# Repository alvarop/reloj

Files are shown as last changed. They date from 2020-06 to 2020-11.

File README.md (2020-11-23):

# Reloj - 7400 Series Digital Clock

This project was inspired by my dad's university digital systems project from the late 1970's. I found the writeup and schematic and decided to try and re-create it. You can see the results of the breadboard reproduction and explanations in [this twitter thread.](https://twitter.com/alvaroprieto/status/1239990814320680960)

After a while, I figured it would be fun to make a soldering kit out of it, which resulted in this.

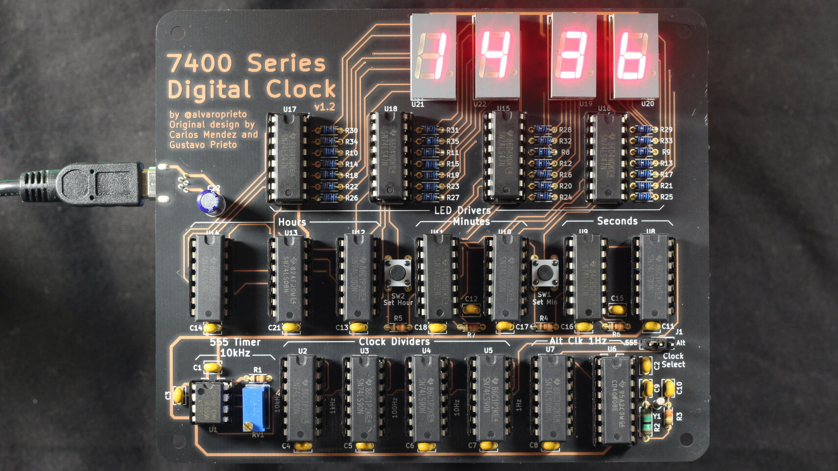
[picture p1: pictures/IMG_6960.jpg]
Reloj v1.2


The design is fairly close to the original, but with the addition of a crystal-backed alternate clock source. The 555 timer clock source works, but drifts like crazy, so if you want to use it as an actual clock, you still can with the alt source.

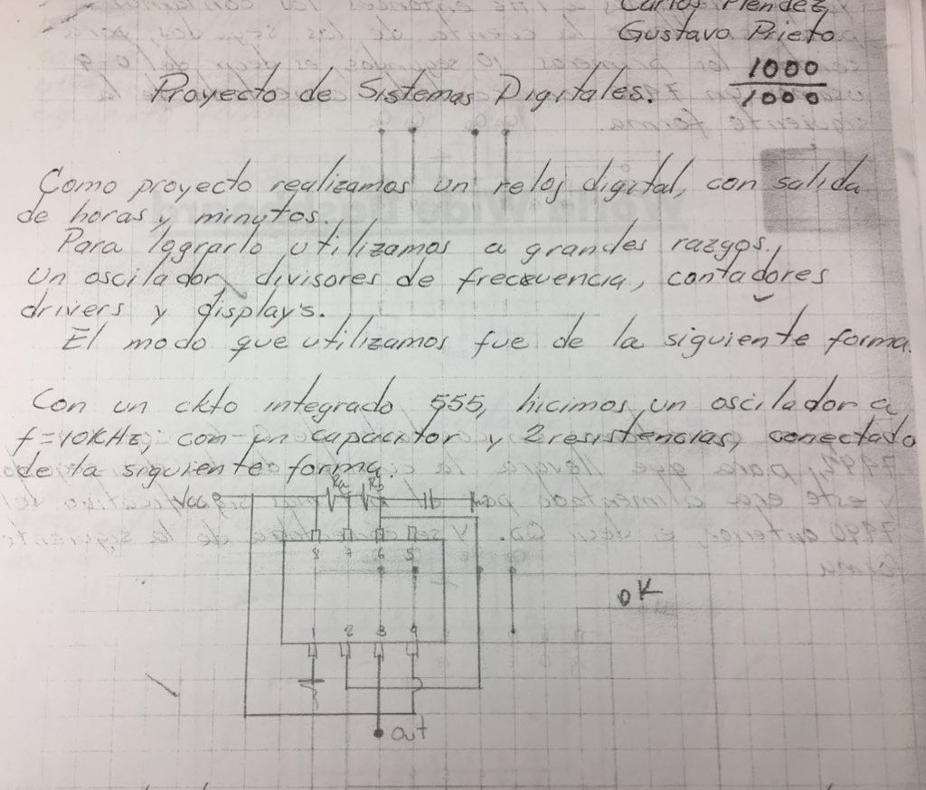
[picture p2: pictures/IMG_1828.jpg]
Paper front page


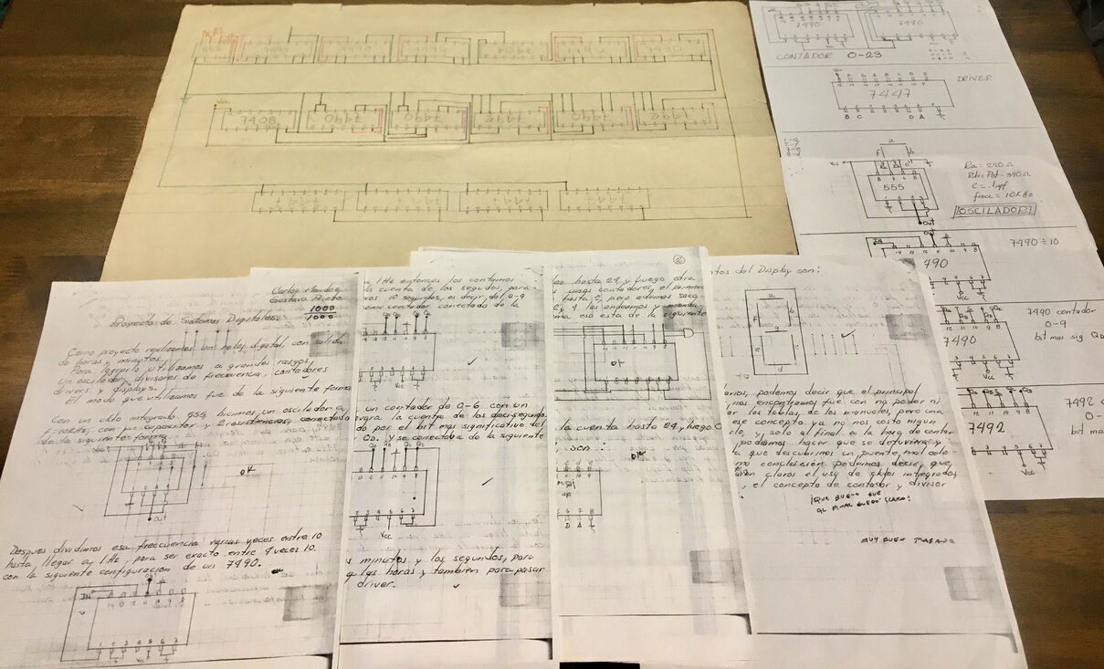
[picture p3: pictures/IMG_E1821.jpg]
Papers


If you want to take a look at the actual paper, you can see the scanned version [here](files/sistemas_digitales.pdf).

## Design Files
You can get the latest files in the [github releases](https://github.com/alvarop/reloj/releases).

For v1.2, you can use my [OSHPark shared project](https://oshpark.com/shared_projects/LdUSEX5V) or by grabbing the gerbers from the release.

## Assembly Instructions
You can find semi-detailed assembly instructions [here](INSTRUCTIONS.md).

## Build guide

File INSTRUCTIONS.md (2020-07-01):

# Reloj v1.2 Assembly Instructions

## Gather Materials
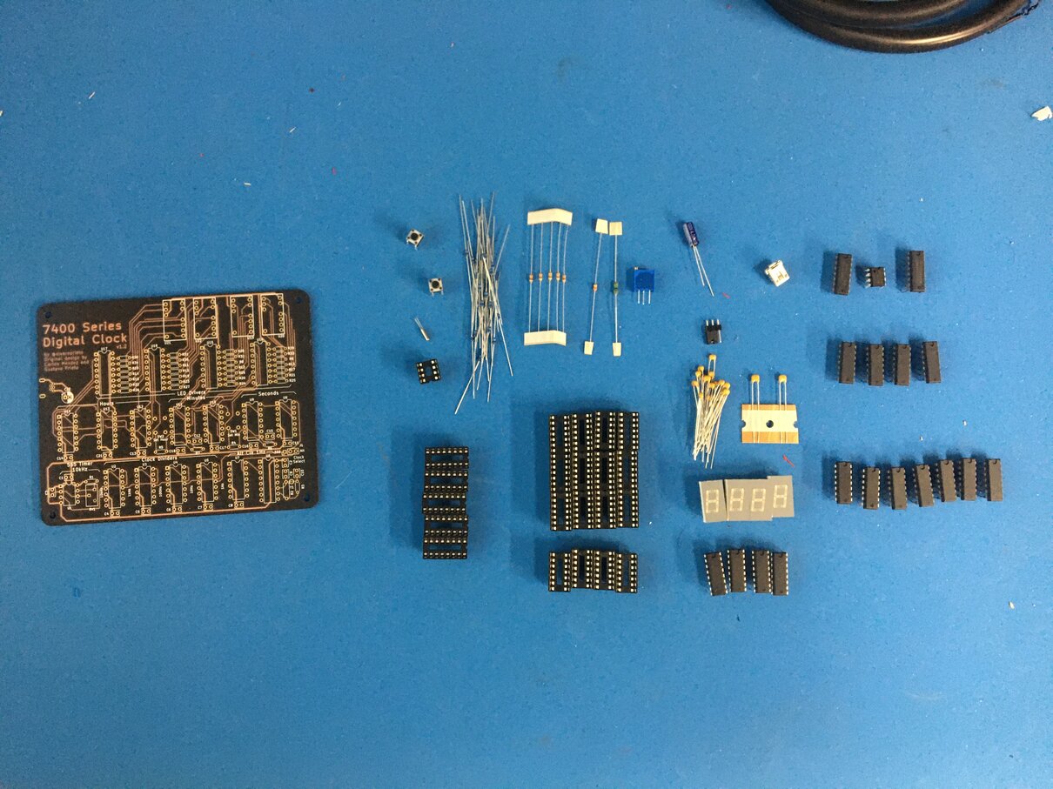
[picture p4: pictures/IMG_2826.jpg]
Materials


Check the BOM and make sure you have all the required components.

**NOTE:** The IC sockets are optional, but do make debugging, repair, etc. much simpler in the end. You will have to modify the sockets for U19-U22 to fit the 7-segment LED footprints.

You can also watch a quick timelapse of the assembly here:

Assembly timelapse (http://www.youtube.com/watch?v=cL3z2LXaWJE)

## Start Soldering!

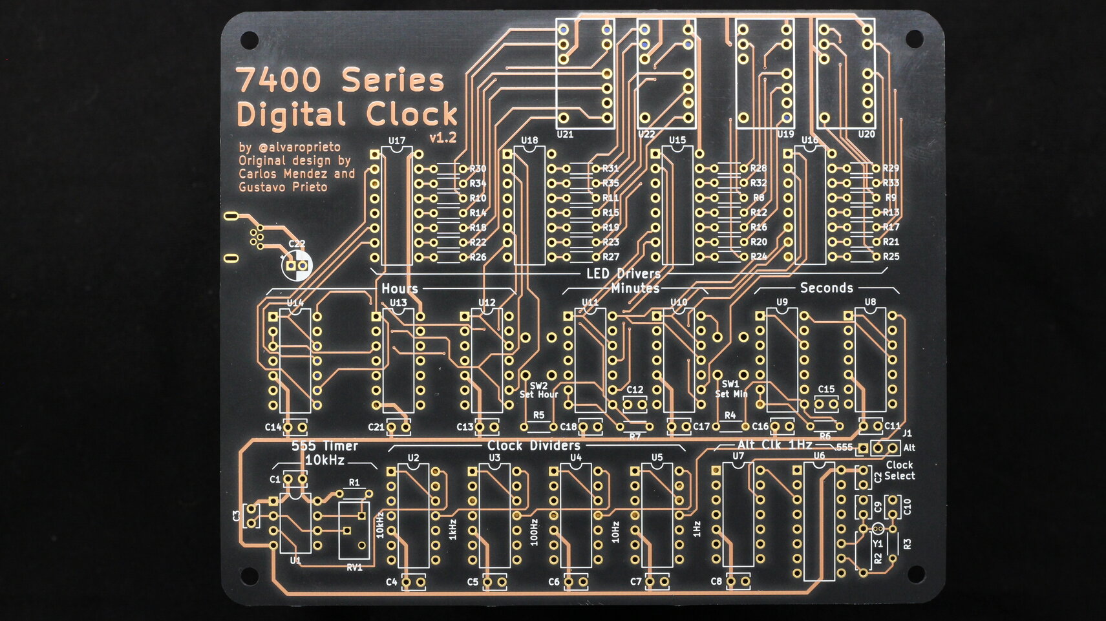
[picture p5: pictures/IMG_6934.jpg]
Bare board


I usually start with the lowest profile components so that I can flip the board over before soldering and they don't fall out as easily. In this case, start with R3.

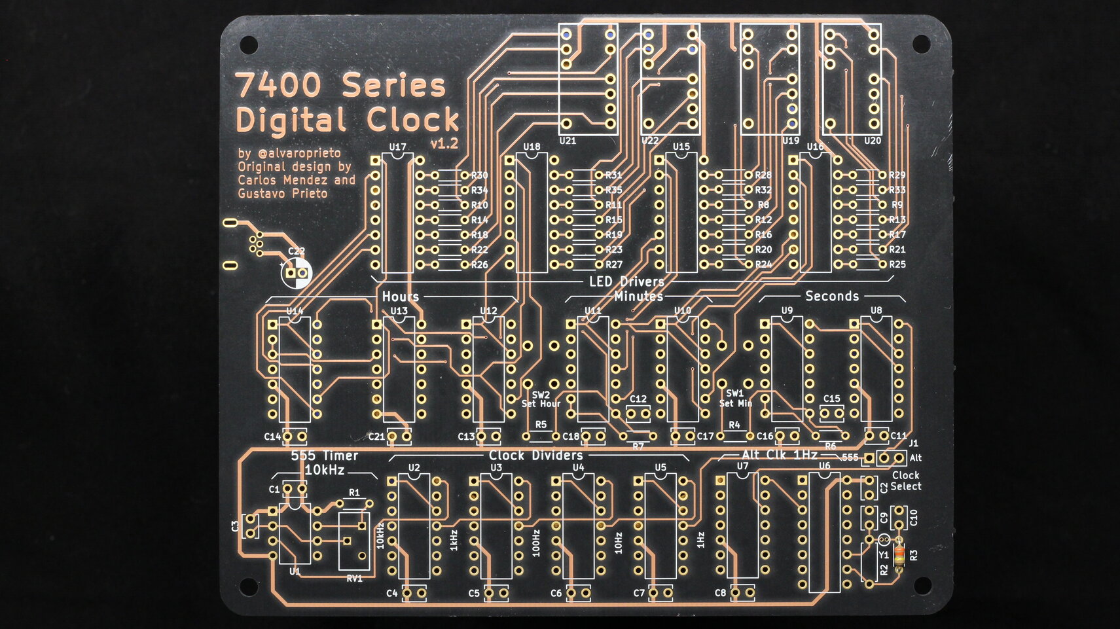
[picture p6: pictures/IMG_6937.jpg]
R3


I usually put all the components I plan on soldering in a particular stage and bend the leads on the other side to hold them in place while flipping the board over.

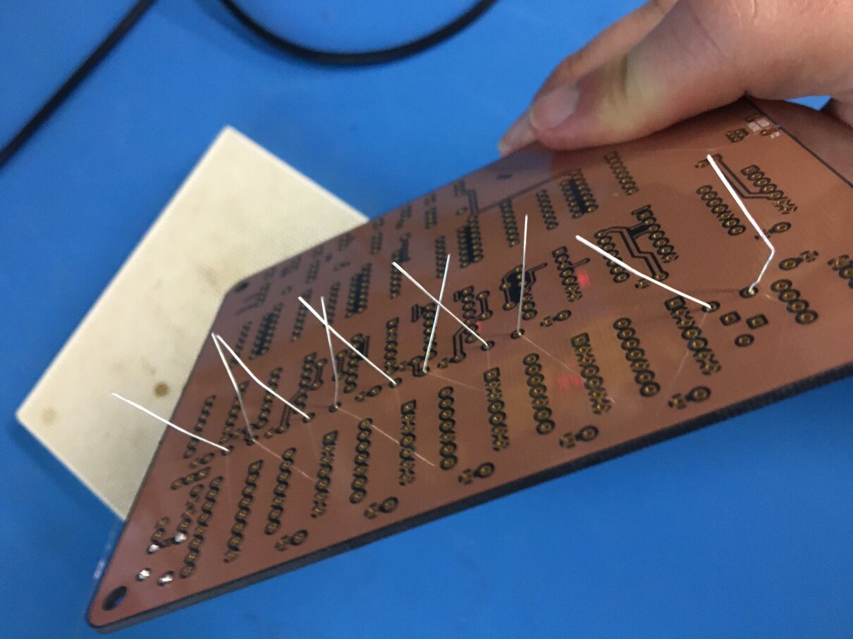
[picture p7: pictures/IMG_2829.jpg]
Bent leads example


Continue with R2.

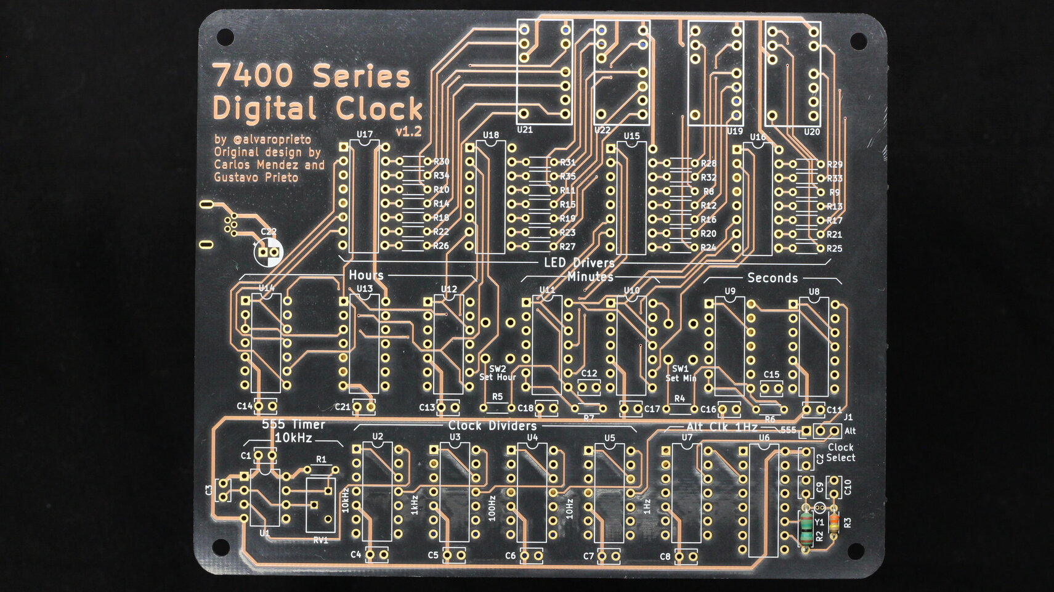
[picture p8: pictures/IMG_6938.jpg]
R2


Next place R4, R5, R6, R7.

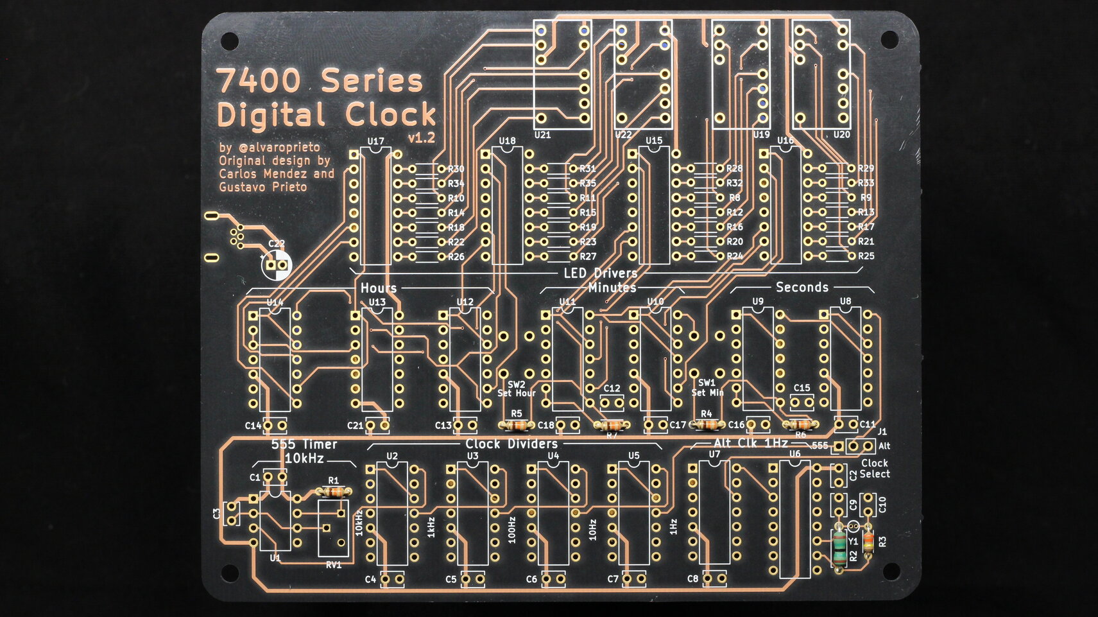
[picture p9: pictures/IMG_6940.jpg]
R4-R7


The LED resistors come next. R8-R35. I did them in four stages to give myself room to solder. You could also do every other column at a time.

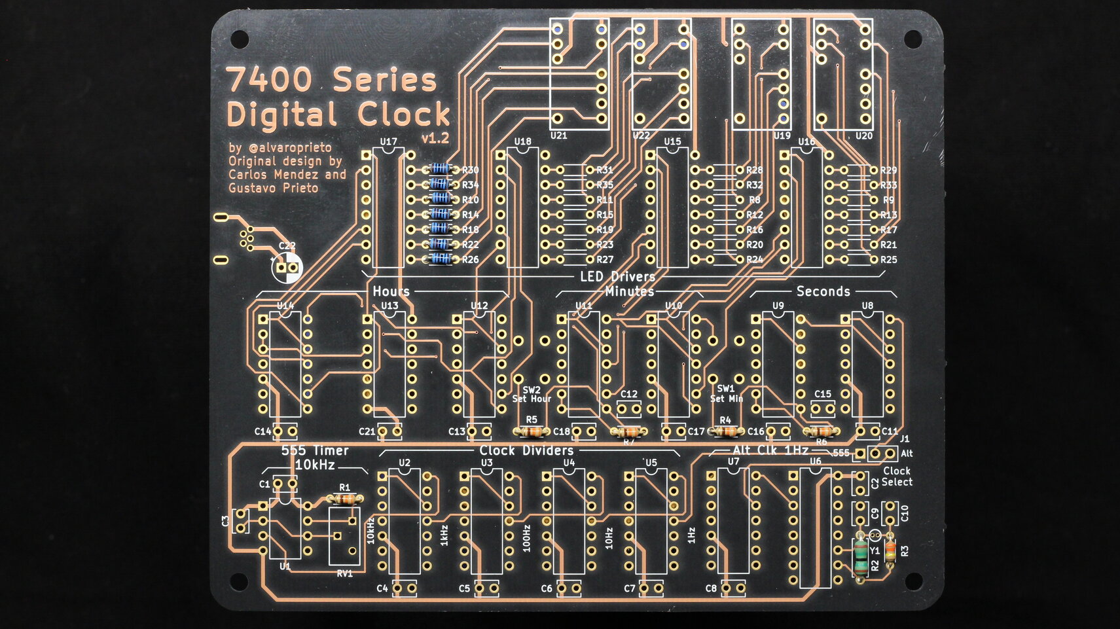
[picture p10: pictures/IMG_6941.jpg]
LED Resistors 1


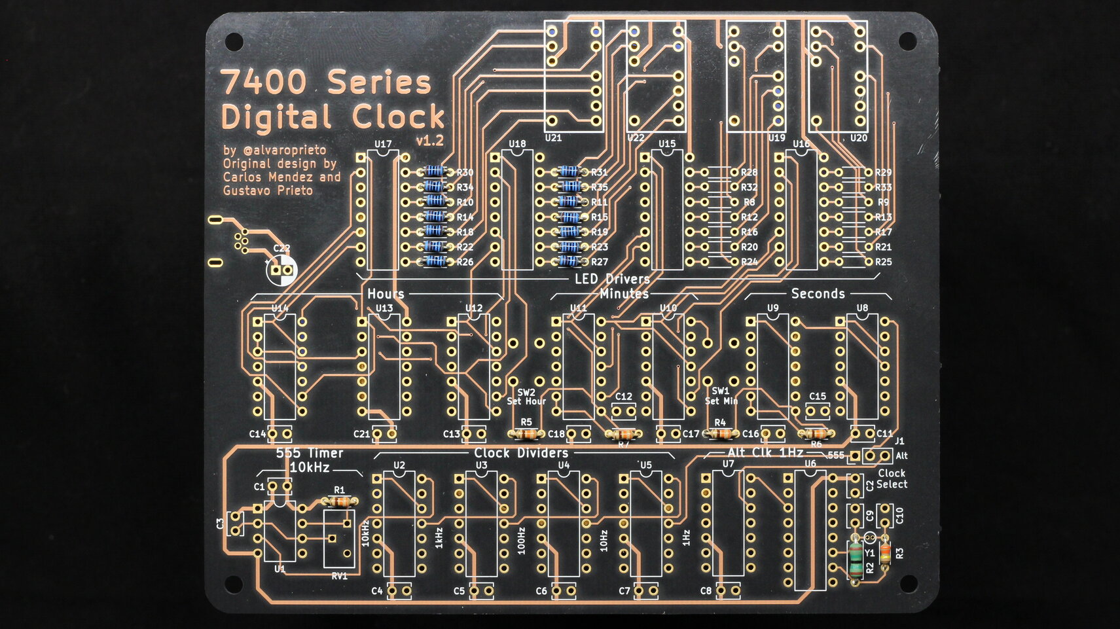
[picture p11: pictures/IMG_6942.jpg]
LED Resistors 2


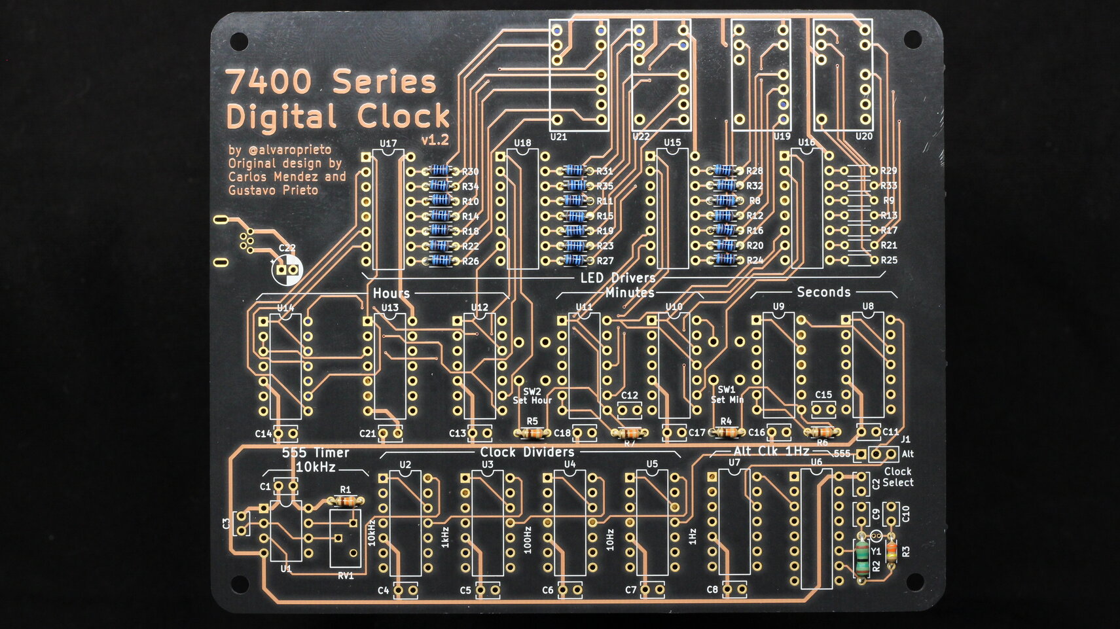
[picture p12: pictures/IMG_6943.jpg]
LED Resistors 3


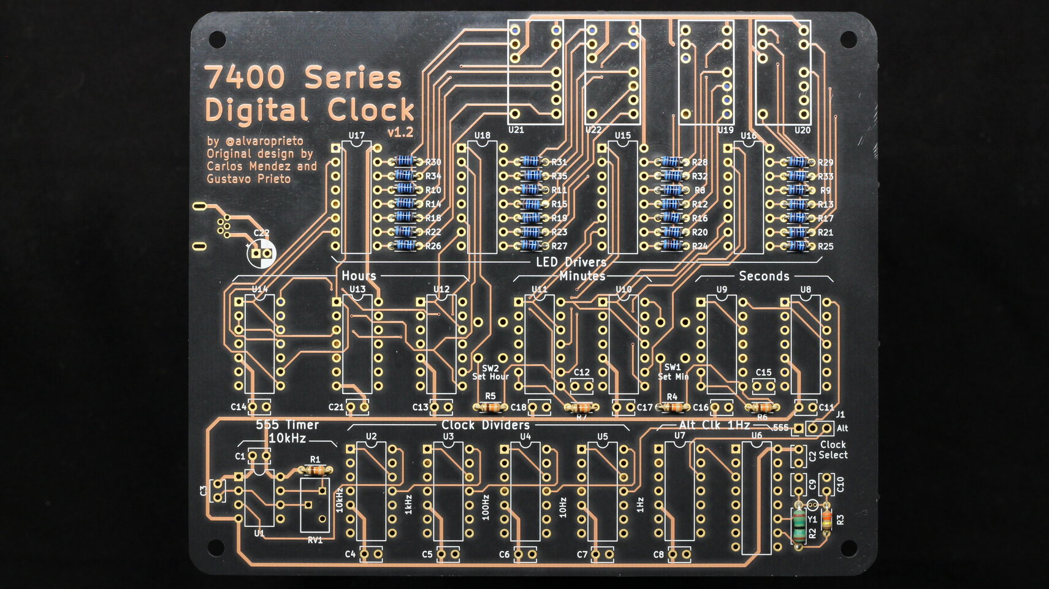
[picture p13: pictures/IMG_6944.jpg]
LED Resistors 4


That's all the resistors. Next place C9 and C10.

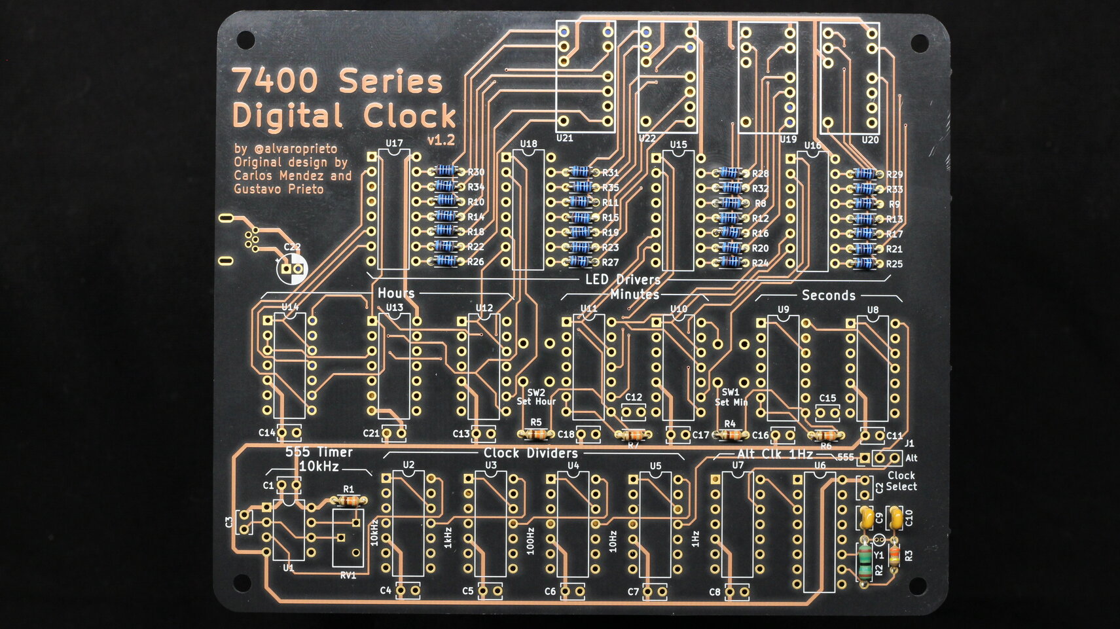
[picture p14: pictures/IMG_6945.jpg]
C9, C10


Now come the rest of the capacitors. (C1,C2,C3,C4,C5,C6,C7,C8,C11,C12,C13,C14,C15,C16,C17,C18,C21)

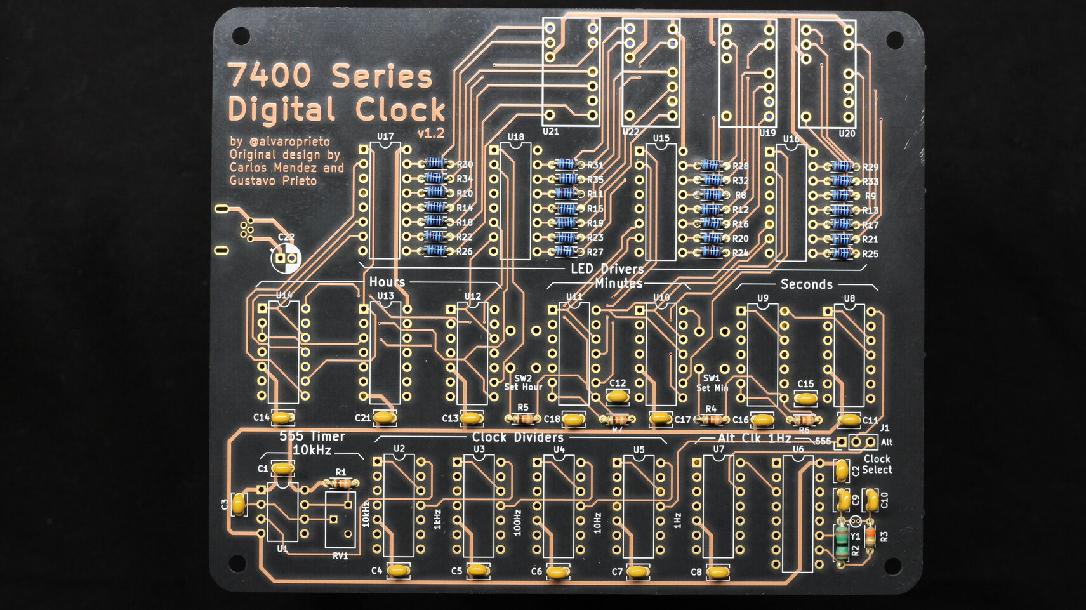
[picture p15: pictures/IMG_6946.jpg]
C1,C2,C3,C4,C5,C6,C7,C8,C11,C12,C13,C14,C15,C16,C17,C18,C21


Time to install the IC sockets!

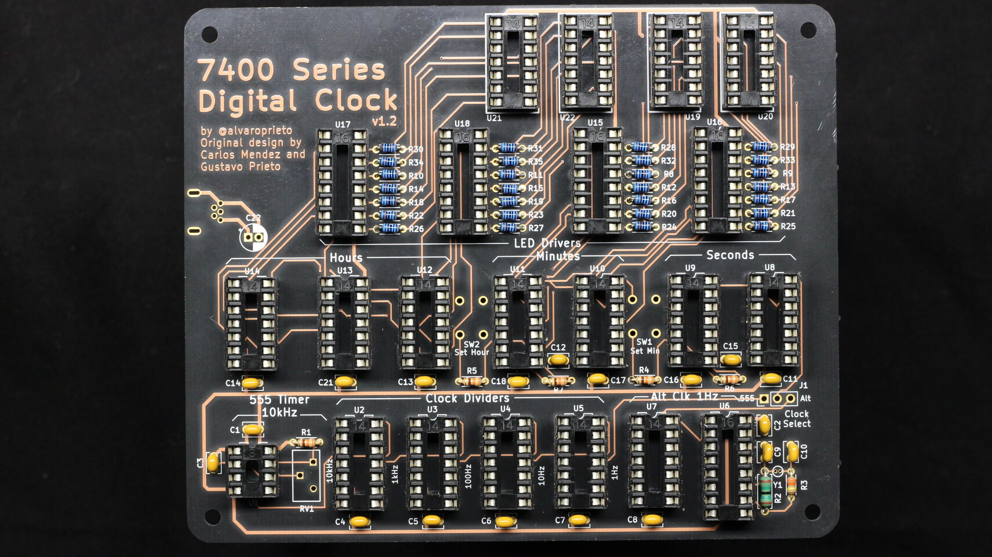
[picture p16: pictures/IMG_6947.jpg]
IC Sockets


Before installing the sockets for U19-U22, cut off the extra leads so they fit in the socket.

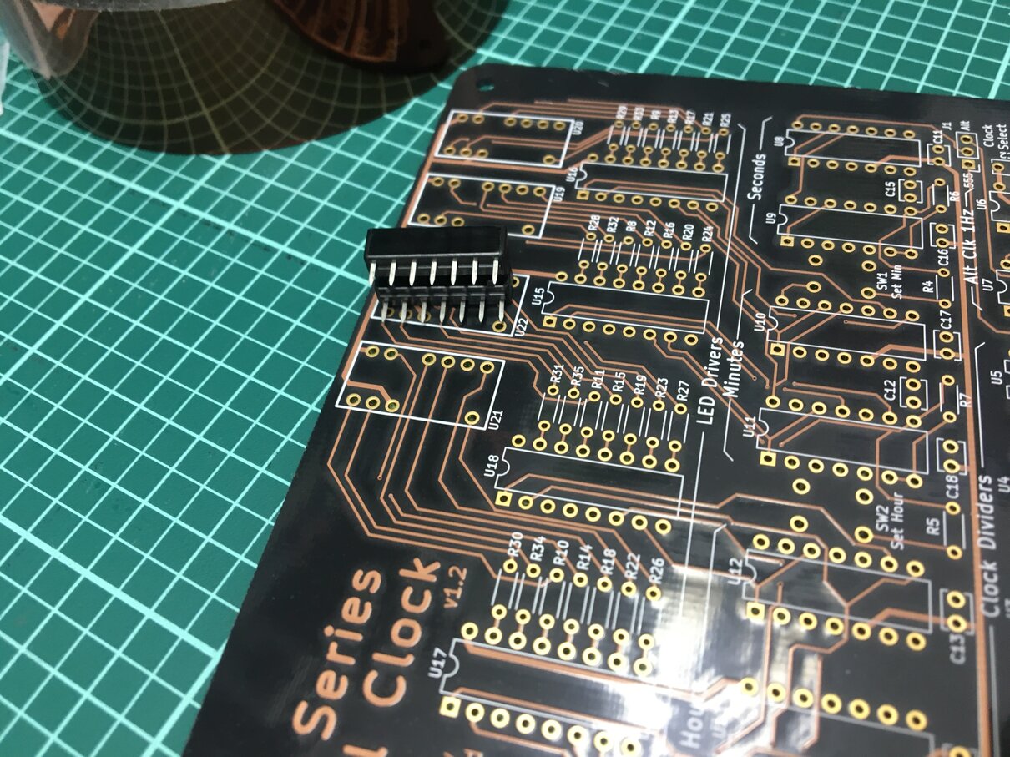
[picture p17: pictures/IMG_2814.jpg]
Socket before modification


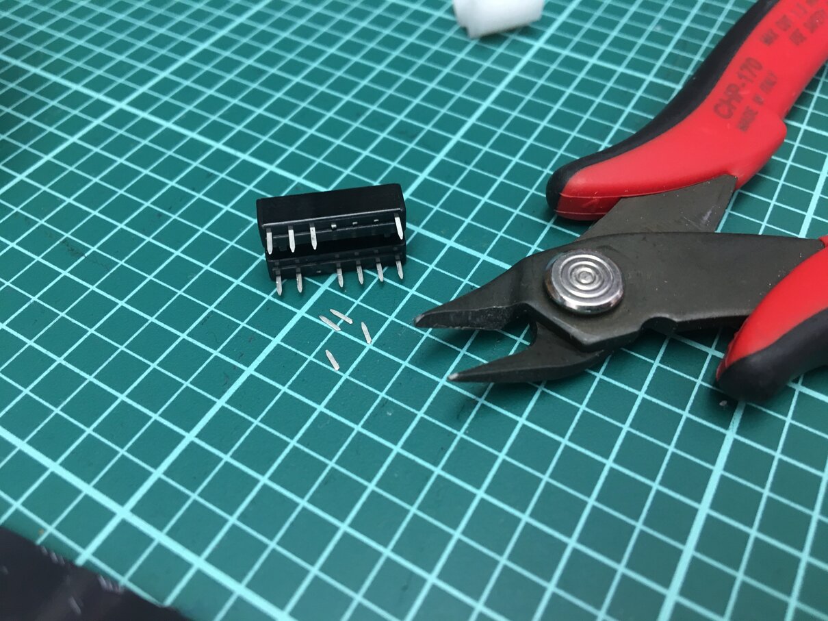
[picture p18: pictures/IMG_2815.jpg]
Socket modification


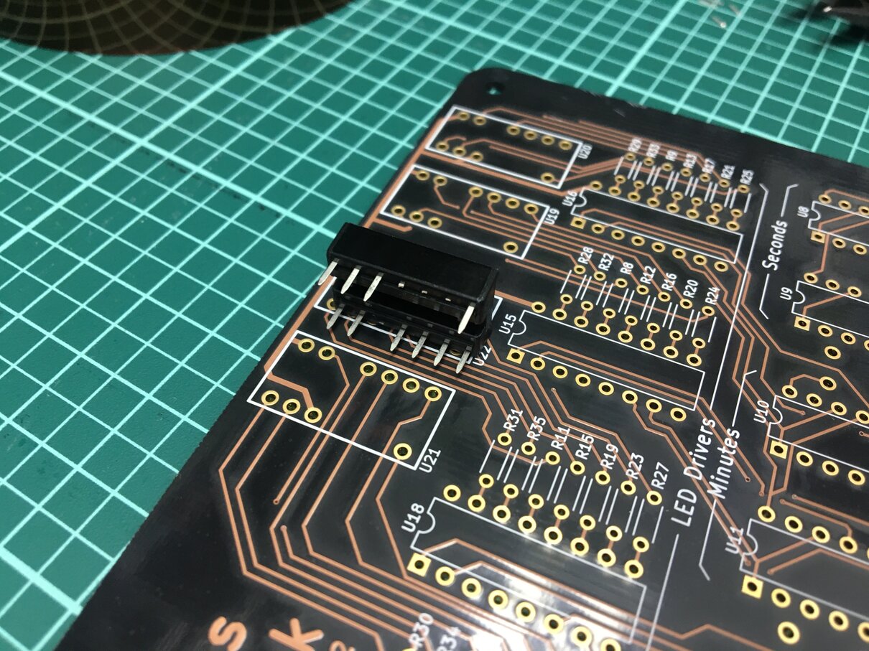
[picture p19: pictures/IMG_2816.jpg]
Socket after modification


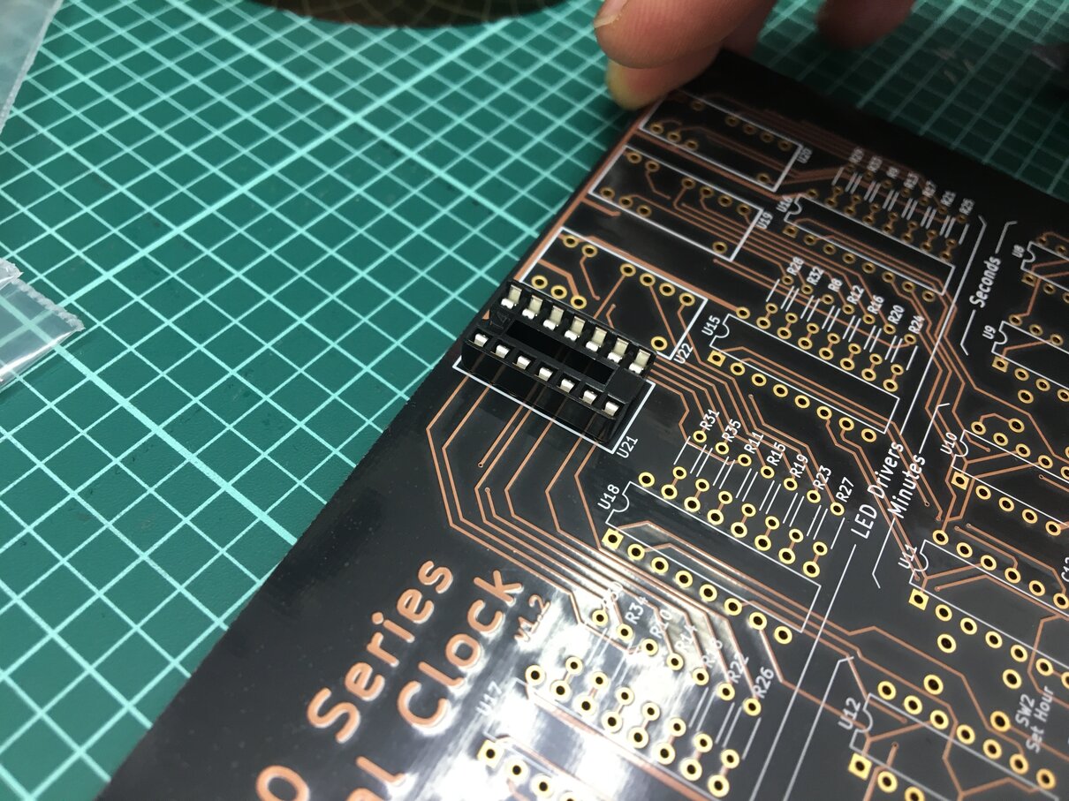
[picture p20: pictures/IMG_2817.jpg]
Socket in place


Time to install the two buttons.

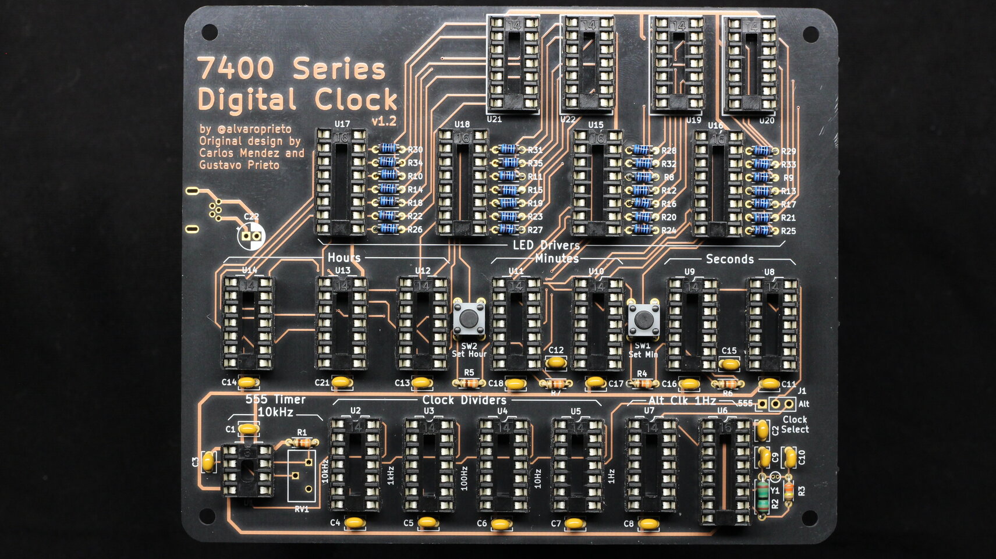
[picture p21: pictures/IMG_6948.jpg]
Buttons


Next comes the tiny crystal Y1. I also forgot to take a picture in between but after the crystal install the pin headers J1.
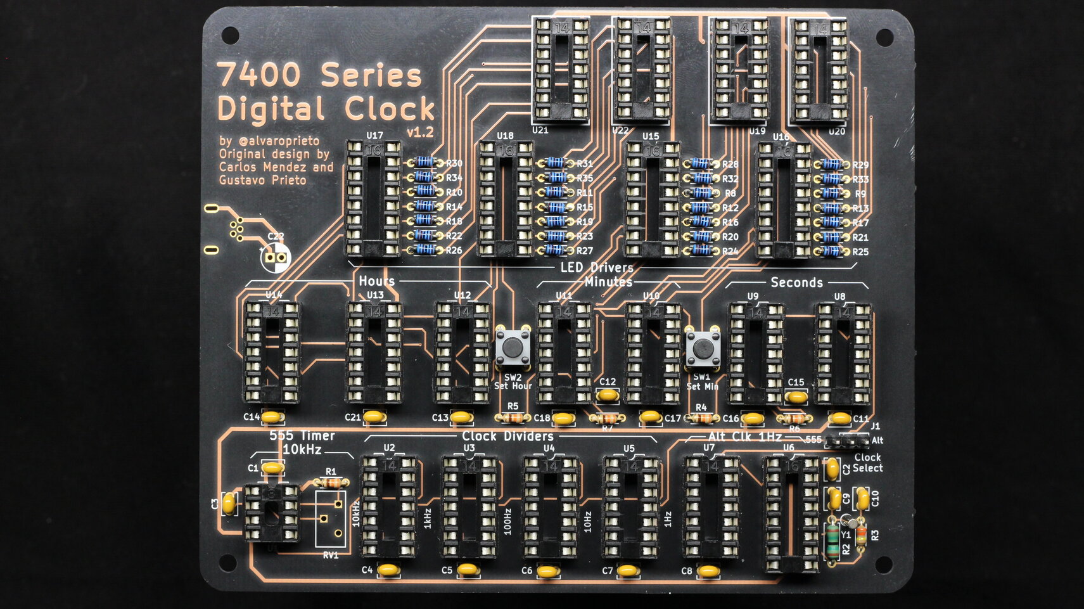
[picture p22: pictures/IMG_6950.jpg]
Y1, J1


Now comes the potentiometer RV1.
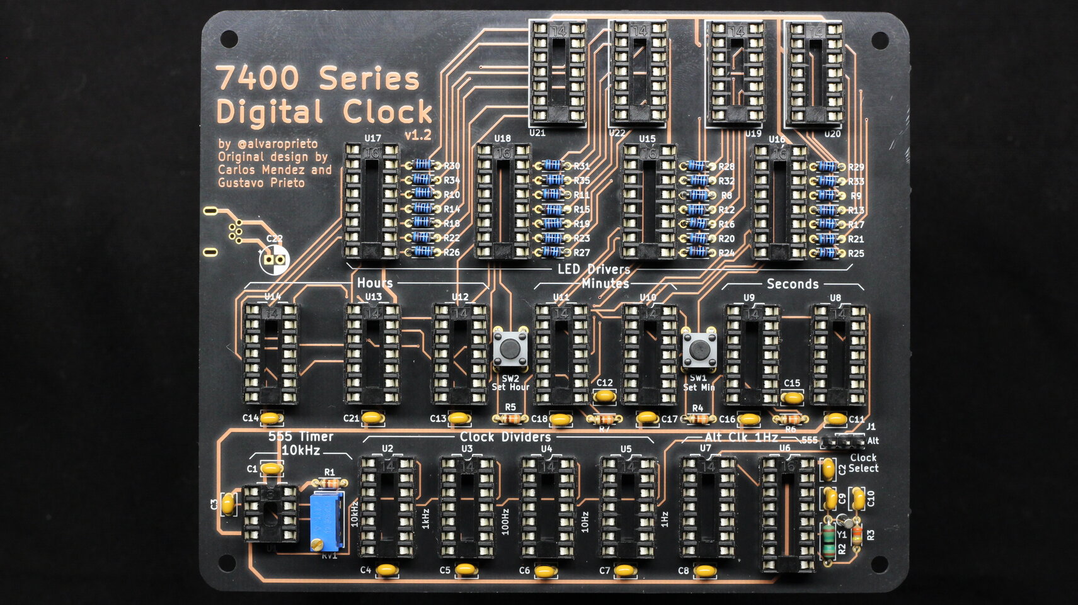
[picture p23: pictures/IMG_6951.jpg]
RV1


Finally, the last component on this side, the electrolytic capacitor C22. Make sure the shorter lead goes in the negative side (filled in white silkscreen).

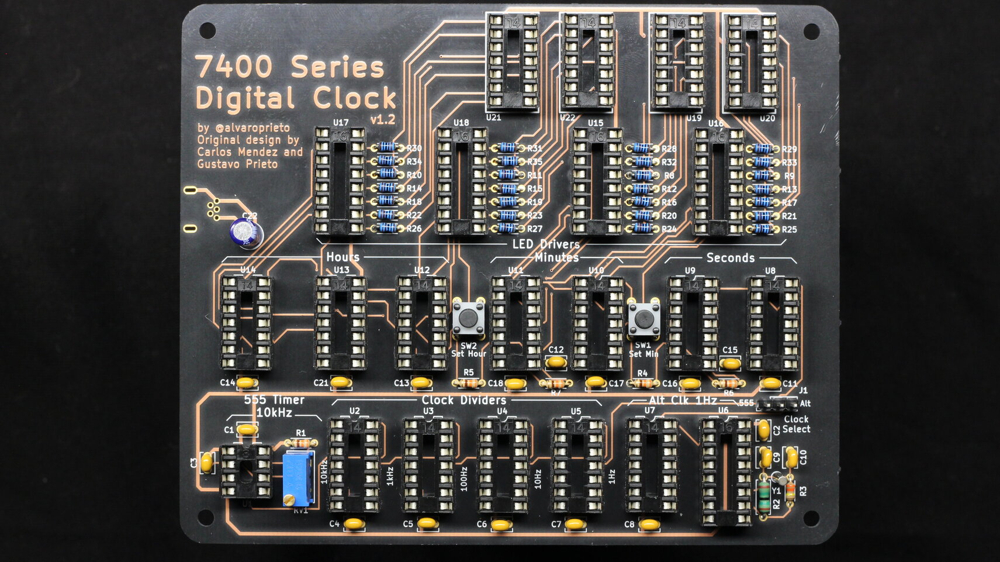
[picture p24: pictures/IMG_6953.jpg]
C22


Before soldering the USB connector J2, make sure you flip the board! The footprint can go on both ways, which is unfortunate.

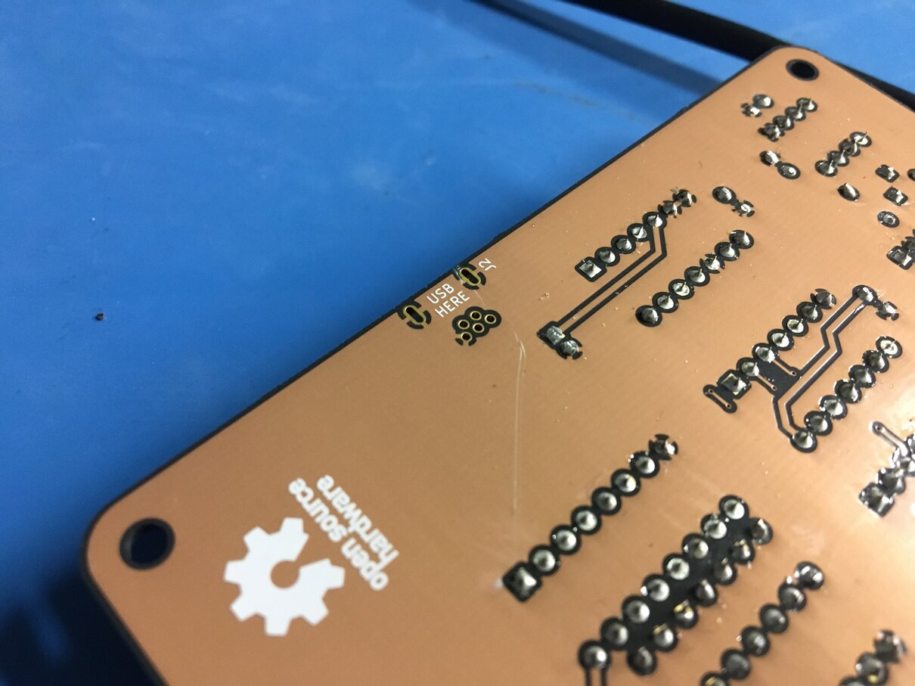
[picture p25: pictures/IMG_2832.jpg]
USB Footprint


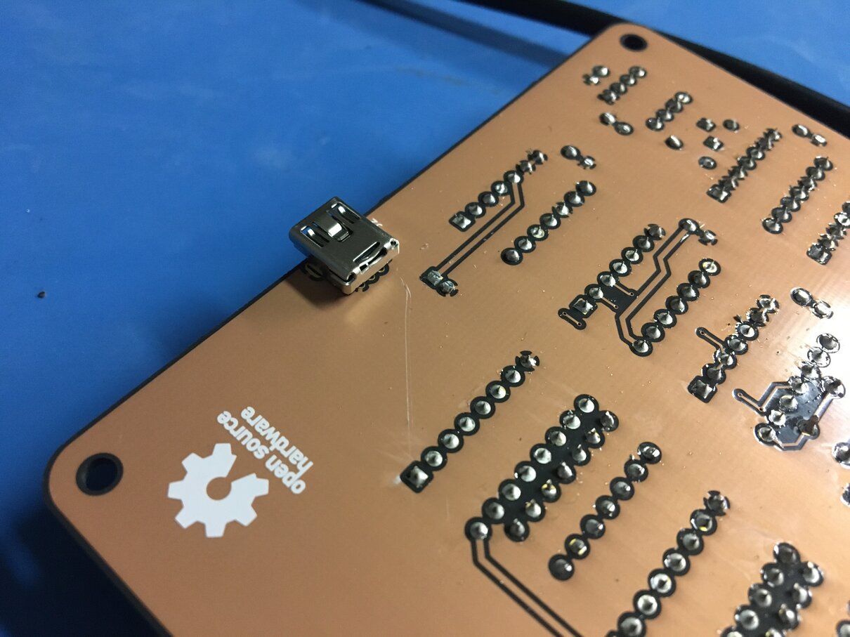
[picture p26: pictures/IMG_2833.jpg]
USB Connector


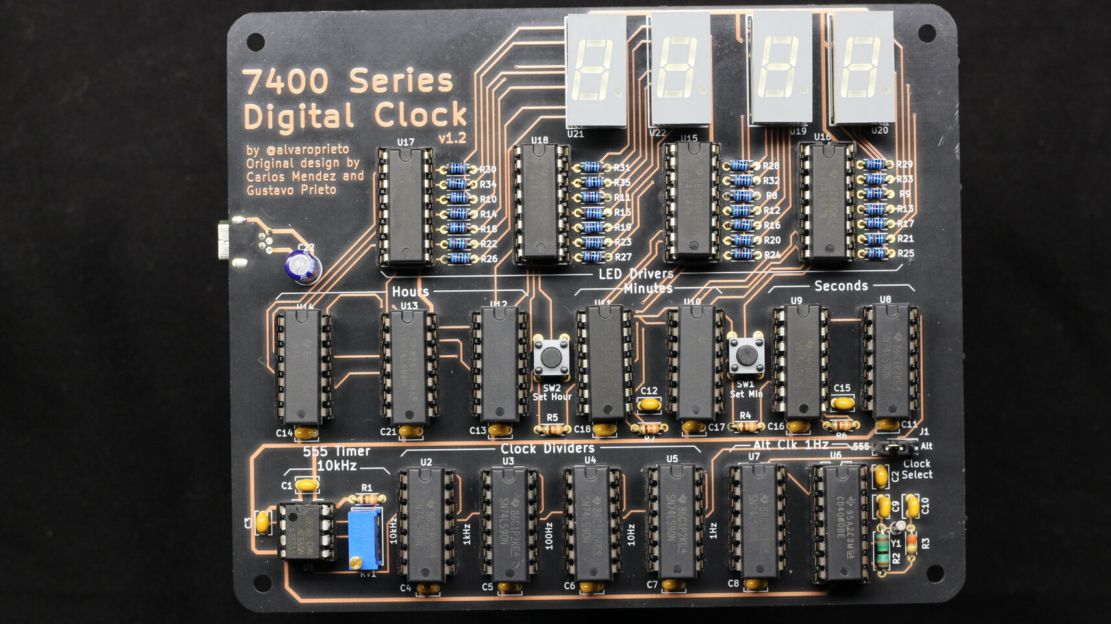
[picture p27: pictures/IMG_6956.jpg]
Finished!


Time to put in the jumper on J1 to select your clock. You can use the full 7400-series path with the 555 timer as the clock source or the "Alt" clock that uses the crystal oscillator for much lower drift.

That's it! If you happen to have a current-limited power supply, use that to power it up first.

## Adjusting the clock
Potentiometer RV1 can be used to adjust the 10kHz clock source. You'll need a frequency counter, oscilloscope, or other equipment to monitor this while you adjust.

To increment the minute count, press SW1. To increment the hours, press SW2. There's no button debouncing, so sometimes the value will go up by more than one.

When you first power it up, the clocks might read impossible times like **75:89**. That's ok. Just use the buttons to increment them until they reset back to 0.

## Troubleshooting
If things aren't working, first make sure all the IC's are inserted correctly. Notch up and no bent pins. Make sure the clock select jumper is in place as well.

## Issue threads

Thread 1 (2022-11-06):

Hello!

gvanrossum, 2022-11-06:
Your show-and-tell talk reminded me of a similar project I did while in high school, around 1973.

Together with the two other nerds in our high school class we built an accurate digital timer (not a clock!) using very similar 7400 circuitry. The timer did not use a 555 IC (those didn't exist AFAIR) but we used the AC coming out of the transformer in the power supply, tapping the rectified but unsmoothed voltage. In Europe AC is 50 Hz, so rectified this was 100 Hz, which made the counting easy.

Instead of 7-segment displays (which existed but were expensive so I had no experience with them) we used BCD for the readout using 6V 0.05W lightbulbs. I don't recall what we used for drivers, probably a simple transistor per bit. We had four BCD "digits", allowing us to measure times up to 100 seconds, with 0.01 second precision.

The lab assistant helped by making a sturdy case, and the physics teacher (our favorite!) used it to help lower classes measure the force and acceleration of gravity. (And teach them counting in binary at the same time. :-)

Ah, nostalgia! Feel free to close this after reading.

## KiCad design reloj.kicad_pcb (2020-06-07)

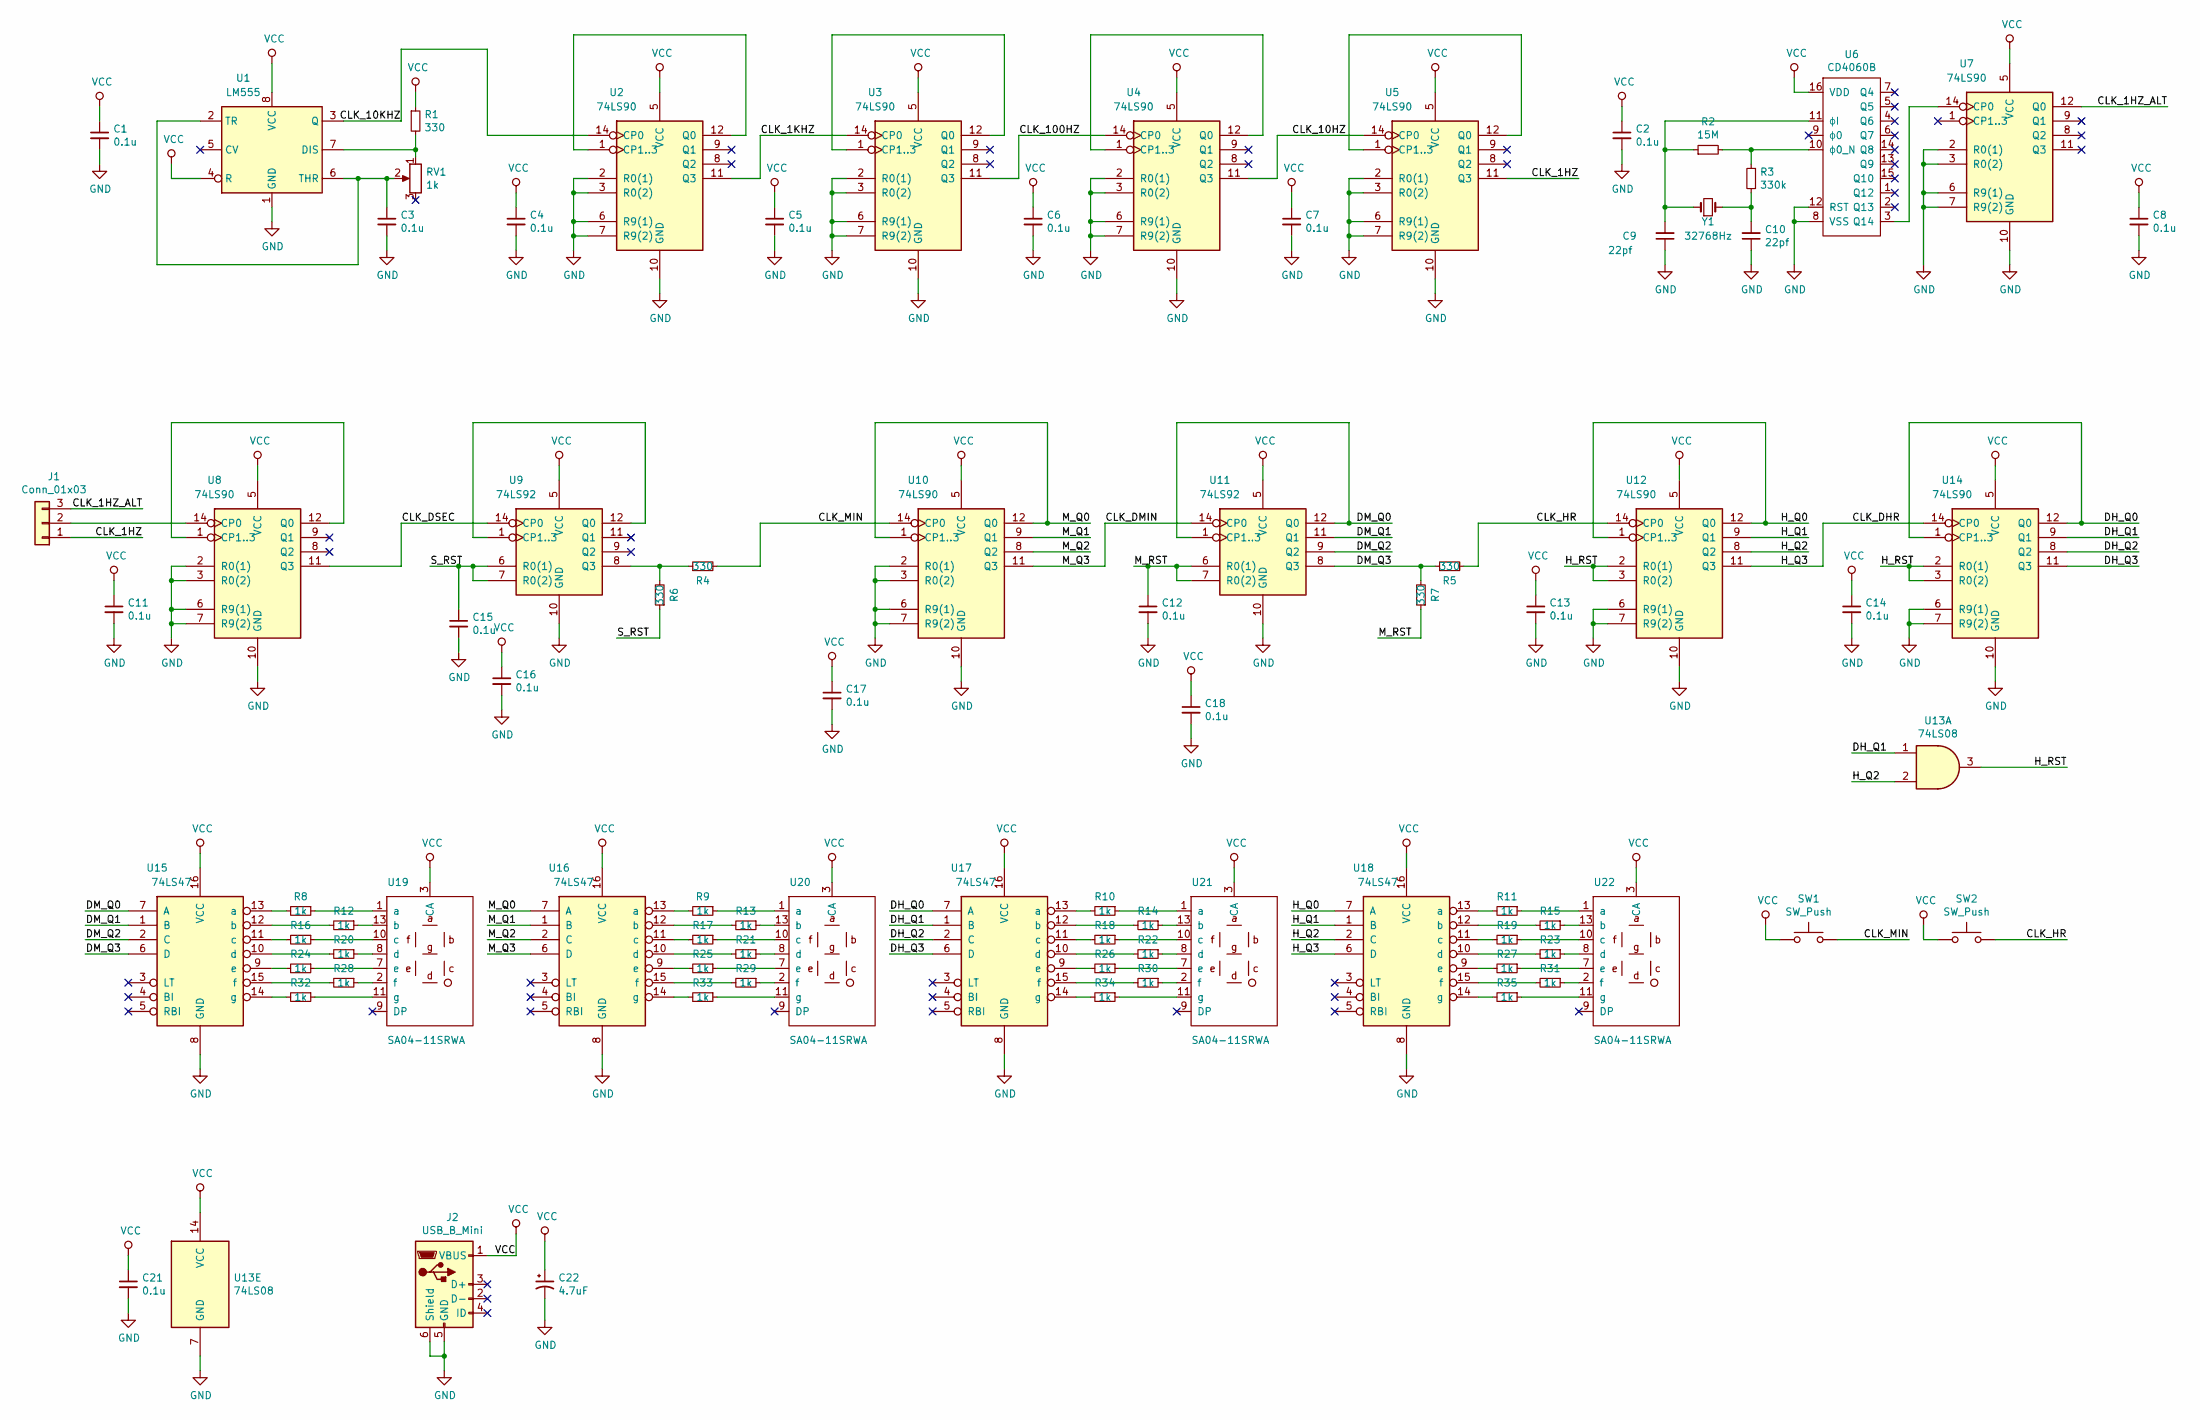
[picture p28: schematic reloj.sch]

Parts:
C1, C2, C3, C4, C5, C6, C7, C8, C11, C12, C13, C14, C15, C16, C17, C18, C21: 0.1u; C_Disc_D3.8mm_W2.6mm_P2.50mm; MPN K104K15X7RF53L2
C9, C10: 22pf; C_Disc_D3.8mm_W2.6mm_P2.50mm; MPN ‎K220J15C0GF5TL2‎
C22: 4.7uF; CP_Radial_D5.0mm_P2.00mm; MPN ECA-2AM4R7
J1: Conn_01x03; PinHeader_1x03_P2.54mm_Vertical
J2: USB_B_Mini; TE_2172034-1; MPN ‎2172034-1‎
R1, R4, R5, R6, R7: 330; R_Axial_DIN0204_L3.6mm_D1.6mm_P5.08mm_Horizontal; MPN ‎CF18JT330R‎
R2: 15M; R_Axial_DIN0207_L6.3mm_D2.5mm_P7.62mm_Horizontal; MPN ‎RNV14FAL15M0‎
R3: 330k; R_Axial_DIN0204_L3.6mm_D1.6mm_P5.08mm_Horizontal; MPN ‎CF18JT330K‎
R8, R9, R10, R11, R12, R13, R14, R15, R16, R17, R18, R19, R20, R21, R22, R23, R24, R25, R26, R27, R28, R29, R30, R31, R32, R33, R34, R35: 1k; R_Axial_DIN0204_L3.6mm_D1.6mm_P5.08mm_Horizontal; MPN ‎CF18JT1K00
RV1: 1k; 3296Y-1-102LF; MPN 3296Y-1-102LF
SW1, SW2: SW_Push; TE_1825910-6; MPN 1825910-6
U1: LM555; DIP-8_W7.62mm; MPN NE555P
U2, U3, U4, U5, U7, U8, U10, U12, U14: 74LS90; DIP-14_W7.62mm; MPN ‎SN74LS90N‎
U6: CD4060B; DIP-16_W7.62mm; MPN ‎CD4060BE‎
U9, U11: 74LS92; DIP-14_W7.62mm; MPN ‎SN74LS92N‎
U13: 74LS08; DIP-14_W7.62mm; MPN ‎SN74LS08N‎
U15, U16, U17, U18: 74LS47; DIP-16_W7.62mm; MPN ‎SN74LS47N‎
U19, U20, U21, U22: SA04-11SRWA; MPN SA04-11SRWA‎
Y1: 32768Hz; CFS-206x; MPN CFS-20632768DZFB‎

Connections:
/CLK_1HZ: J1.1, U5.11 (Q3)
/CLK_1HZ_ALT: J1.3, U7.12 (Q0)
/CLK_1KHZ: U2.11 (Q3), U3.14 (CP0)
/CLK_10HZ: U4.11 (Q3), U5.14 (CP0)
/CLK_10KHZ: U1.3 (Q), U2.14 (CP0)
/CLK_100HZ: U3.11 (Q3), U4.14 (CP0)
/CLK_DHR: U12.11 (Q3), U14.14 (CP0), U18.6 (D)
/CLK_DMIN: U10.11 (Q3), U11.14 (CP0), U16.6 (D)
/CLK_DSEC: U8.11 (Q3), U9.14 (CP0)
/CLK_HR: R5.2, SW2.2, U12.14 (CP0)
/CLK_MIN: R4.2, SW1.2, U10.14 (CP0)
/DH_Q0: U14.1 (CP1..3), U14.12 (Q0), U17.7 (A)
/DH_Q1: U13.1, U14.9 (Q1), U17.1 (B)
/DH_Q2: U14.8 (Q2), U17.2 (C)
/DH_Q3: U14.11 (Q3), U17.6 (D)
/DM_Q0: U11.1 (CP1..3), U11.12 (Q0), U15.7 (A)
/DM_Q1: U11.11 (Q1), U15.1 (B)
/DM_Q2: U11.9 (Q2), U15.2 (C)
/DM_Q3: R5.1, R7.2, U11.8 (Q3), U15.6 (D)
/H_Q0: U12.1 (CP1..3), U12.12 (Q0), U18.7 (A)
/H_Q1: U12.9 (Q1), U18.1 (B)
/H_Q2: U12.8 (Q2), U13.2, U18.2 (C)
/H_RST: U12.2 (R0(1)), U12.3 (R0(2)), U13.3, U14.2 (R0(1)), U14.3 (R0(2))
/M_Q0: U10.1 (CP1..3), U10.12 (Q0), U16.7 (A)
/M_Q1: U10.9 (Q1), U16.1 (B)
/M_Q2: U10.8 (Q2), U16.2 (C)
/M_RST: C12.1, R7.1, U11.6 (R0(1)), U11.7 (R0(2))
/S_RST: C15.1, R6.1, U9.6 (R0(1)), U9.7 (R0(2))
CA: C1.1, C2.1, C4.1, C5.1, C6.1, C7.1, C8.1, C11.1, C13.1, C14.1, C16.1, C17.1, C18.1, C21.1, C22.1, J2.1 (VBUS), R1.1, SW1.1, SW2.1, U1.4 (R), U1.8 (VCC), U2.5 (VCC), U3.5 (VCC), U4.5 (VCC), U5.5 (VCC), U6.16 (VDD), U7.5 (VCC), U8.5 (VCC), U9.5 (VCC), U10.5 (VCC), U11.5 (VCC), U12.5 (VCC), U13.14 (VCC), U14.5 (VCC), U15.16 (VCC), U16.16 (VCC), U17.16 (VCC), U18.16 (VCC), U19.3 (CA), U19.14 (CA), U20.3 (CA), U20.14 (CA), U21.3 (CA), U21.14 (CA), U22.3 (CA), U22.14 (CA)
GND: C1.2, C2.2, C3.2, C4.2, C5.2, C6.2, C7.2, C8.2, C9.1, C10.1, C11.2, C12.2, C13.2, C14.2, C15.2, C16.2, C17.2, C18.2, C21.2, C22.2, J2.5 (GND), J2.6 (Shield), U1.1 (GND), U2.2 (R0(1)), U2.3 (R0(2)), U2.6 (R9(1)), U2.7 (R9(2)), U2.10 (GND), U3.2 (R0(1)), U3.3 (R0(2)), U3.6 (R9(1)), U3.7 (R9(2)), U3.10 (GND), U4.2 (R0(1)), U4.3 (R0(2)), U4.6 (R9(1)), U4.7 (R9(2)), U4.10 (GND), U5.2 (R0(1)), U5.3 (R0(2)), U5.6 (R9(1)), U5.7 (R9(2)), U5.10 (GND), U6.8 (VSS), U6.12 (RST), U7.2 (R0(1)), U7.3 (R0(2)), U7.6 (R9(1)), U7.7 (R9(2)), U7.10 (GND), U8.2 (R0(1)), U8.3 (R0(2)), U8.6 (R9(1)), U8.7 (R9(2)), U8.10 (GND), U9.10 (GND), U10.2 (R0(1)), U10.3 (R0(2)), U10.6 (R9(1)), U10.7 (R9(2)), U10.10 (GND), U11.10 (GND), U12.6 (R9(1)), U12.7 (R9(2)), U12.10 (GND), U13.7 (GND), U14.6 (R9(1)), U14.7 (R9(2)), U14.10 (GND), U15.8 (GND), U16.8 (GND), U17.8 (GND), U18.8 (GND)
unnamed: C3.1, RV1.2, U1.2 (TR), U1.6 (THR)
unnamed: C9.2, R2.1, U6.11 (ϕI), Y1.1
unnamed: C10.2, R3.2, Y1.2
unnamed: J1.2, U8.14 (CP0)
unnamed: R1.2, RV1.1, U1.7 (DIS)
unnamed: R2.2, R3.1, U6.10 (ϕ0_N)
unnamed: R4.1, R6.2, U9.8 (Q3)
unnamed: R8.1, U19.1 (a)
unnamed: R8.2, U15.13 (a)
unnamed: R9.1, U20.1 (a)
unnamed: R9.2, U16.13 (a)
unnamed: R10.1, U21.1 (a)
unnamed: R10.2, U17.13 (a)
unnamed: R11.1, U22.1 (a)
unnamed: R11.2, U18.13 (a)
unnamed: R12.1, U19.13 (b)
unnamed: R12.2, U15.12 (b)
unnamed: R13.1, U20.13 (b)
unnamed: R13.2, U16.12 (b)
unnamed: R14.1, U21.13 (b)
unnamed: R14.2, U17.12 (b)
unnamed: R15.1, U22.13 (b)
unnamed: R15.2, U18.12 (b)
unnamed: R16.1, U19.10 (c)
unnamed: R16.2, U15.11 (c)
unnamed: R17.1, U20.10 (c)
unnamed: R17.2, U16.11 (c)
unnamed: R18.1, U21.10 (c)
unnamed: R18.2, U17.11 (c)
unnamed: R19.1, U22.10 (c)
unnamed: R19.2, U18.11 (c)
unnamed: R20.1, U19.8 (d)
unnamed: R20.2, U15.10 (d)
unnamed: R21.1, U20.8 (d)
unnamed: R21.2, U16.10 (d)
unnamed: R22.1, U21.8 (d)
unnamed: R22.2, U17.10 (d)
unnamed: R23.1, U22.8 (d)
unnamed: R23.2, U18.10 (d)
unnamed: R24.1, U19.7 (e)
unnamed: R24.2, U15.9 (e)
unnamed: R25.1, U20.7 (e)
unnamed: R25.2, U16.9 (e)
unnamed: R26.1, U21.7 (e)
unnamed: R26.2, U17.9 (e)
unnamed: R27.1, U22.7 (e)
unnamed: R27.2, U18.9 (e)
unnamed: R28.1, U19.2 (f)
unnamed: R28.2, U15.15 (f)
unnamed: R29.1, U20.2 (f)
unnamed: R29.2, U16.15 (f)
unnamed: R30.1, U21.2 (f)
unnamed: R30.2, U17.15 (f)
unnamed: R31.1, U22.2 (f)
unnamed: R31.2, U18.15 (f)
unnamed: R32.1, U19.11 (g)
unnamed: R32.2, U15.14 (g)
unnamed: R33.1, U20.11 (g)
unnamed: R33.2, U16.14 (g)
unnamed: R34.1, U21.11 (g)
unnamed: R34.2, U17.14 (g)
unnamed: R35.1, U22.11 (g)
unnamed: R35.2, U18.14 (g)
unnamed: U2.1 (CP1..3), U2.12 (Q0)
unnamed: U3.1 (CP1..3), U3.12 (Q0)
unnamed: U4.1 (CP1..3), U4.12 (Q0)
unnamed: U5.1 (CP1..3), U5.12 (Q0)
unnamed: U6.3 (Q14), U7.14 (CP0)
unnamed: U8.1 (CP1..3), U8.12 (Q0)
unnamed: U9.1 (CP1..3), U9.12 (Q0)

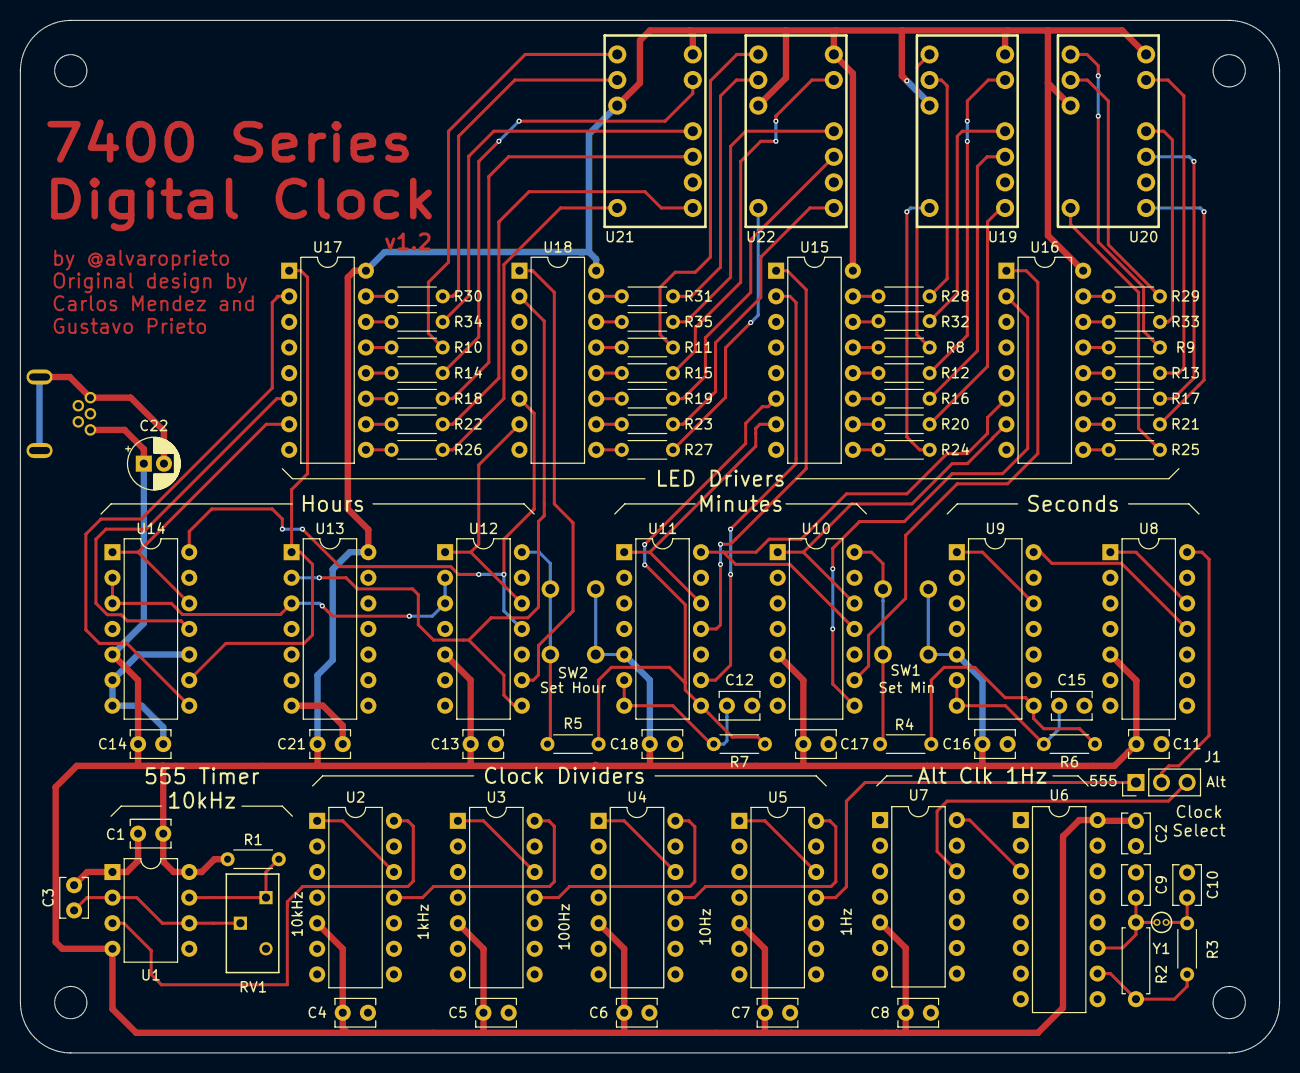
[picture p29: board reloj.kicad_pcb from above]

Board: 2 copper layers, 125.0 x 102.5 mm, 83 parts (1 on the bottom side), 100 nets.

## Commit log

2020-03-23 First commit of reloj. Schematic mostly done
    [reloj.kicad_pcb, reloj.sch]
2020-03-24 Added most BOM items.
    Finished placement on pcb
    [reloj.kicad_pcb, reloj.sch]
2020-04-18 layout updates
    [reloj.kicad_pcb, reloj.sch]
2020-04-26 Added 4.7uF cap and cleaned up traces/silkscreen
    [reloj.kicad_pcb, reloj.sch]
2020-04-28 Finished layout and labels
    DRC passed and verified that remaining non-connected items are
    connected externally by components
    [reloj.kicad_pcb]
2020-05-01 Added OSWH logo and changed title to be on copper layer
    Released to oshpark
    [reloj.kicad_pcb, reloj.sch]
2020-05-18 Fixed BOM
    [reloj.sch]
2020-05-30 Changes for v1.1
    Removed global reset button.
    Connected tens of minutes and tens of second counter resets to their Q3 output via RC filter. This prevents them from resetting themselves before clocking the next device.
    Reduced resistor for CLK_MIN and CLK_HR so that the buttons can still overpower it.
    Moved USB connector to other side and added silkscreen note
    Updated reference designators to make a bit more sense
    NOTE: New resistor values aren't final
    [reloj.kicad_pcb, reloj.sch]
2020-05-30 Forgot to commit changed netlists
    [reloj.kicad_pcb]
2020-06-01 Minor updates to v1.1
    Updated 22pf cap BOM item
    Re-added mounting holes
    Polished a few traces
    Sent out to Bay Area Circuits
    [reloj.kicad_pcb, reloj.sch]
2020-06-06 Starting work on v1.2
    Connected U12's R0 to H_RST. Hours were going from 23->04 since the single digit hour wasn't resetting :/
    Removed both 0.1uF capacitors from CLK_MIN and CLK_HR... Not sure why they ended up there.
    I'm guessing I was thinking of debouncing but they are clock lines so the IC's were behaving poorly.
    [reloj.sch]
2020-06-07 Update layout with v1.2 fixes
    [reloj.kicad_pcb]
2020-06-07 Change LED resistors to 1k to dim them a bit
    Change 555 timer R1 to 330ohm to reduce BOM complexity
    [reloj.sch]
2020-06-07 Switch to groun pour on botom layer
    [reloj.kicad_pcb]

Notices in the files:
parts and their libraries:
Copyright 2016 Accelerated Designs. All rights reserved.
